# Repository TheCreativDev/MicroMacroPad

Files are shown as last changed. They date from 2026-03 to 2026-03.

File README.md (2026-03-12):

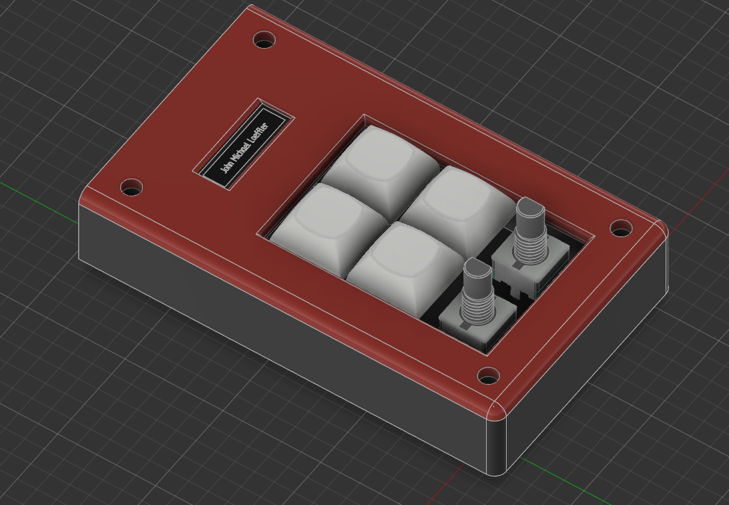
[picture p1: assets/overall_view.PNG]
MiniMacroPad


# Micro-Macro-Pad!

A small design with 4 Switches and 2 Rotary Encoders for maximum freedom with hotkeys. It's the first hardware I designed, and the first time I worked with both KiCad and Autodesk Fusion, but which was easy and fun to get started thanks to the resources on https://blueprint.hackclub.com/hackpad

## Features
- runs on KMK
- added a little animation that flashes the OLED in a wave pattern on every keystroke

## BOM
- 1 Seeed XIAO RP2040
- 4 MX-Style Switches
- 4 blank DSA keycaps
- 2 EC11 Rotary encoders
- 1 0.91 inch OLED display
- 5 M3x16mm screws
- 5 M3x5mmx4mm heatset inserts
- 6 1N4148 Diodes

## Images of the pad

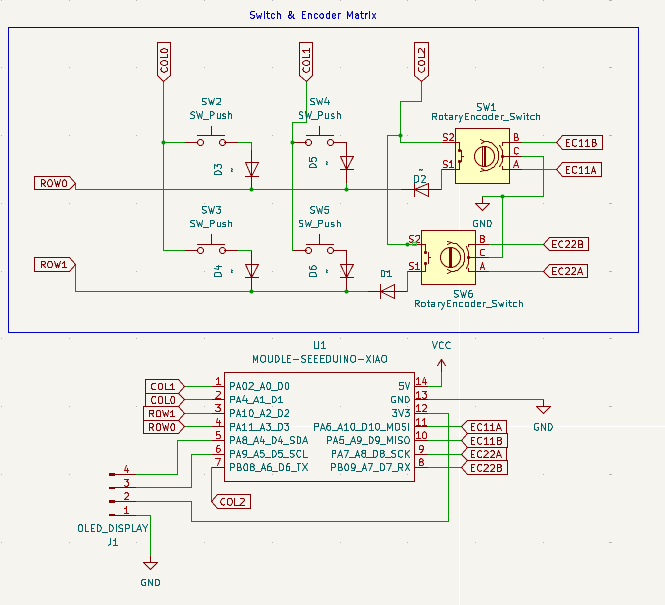
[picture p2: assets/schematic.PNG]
Schematic

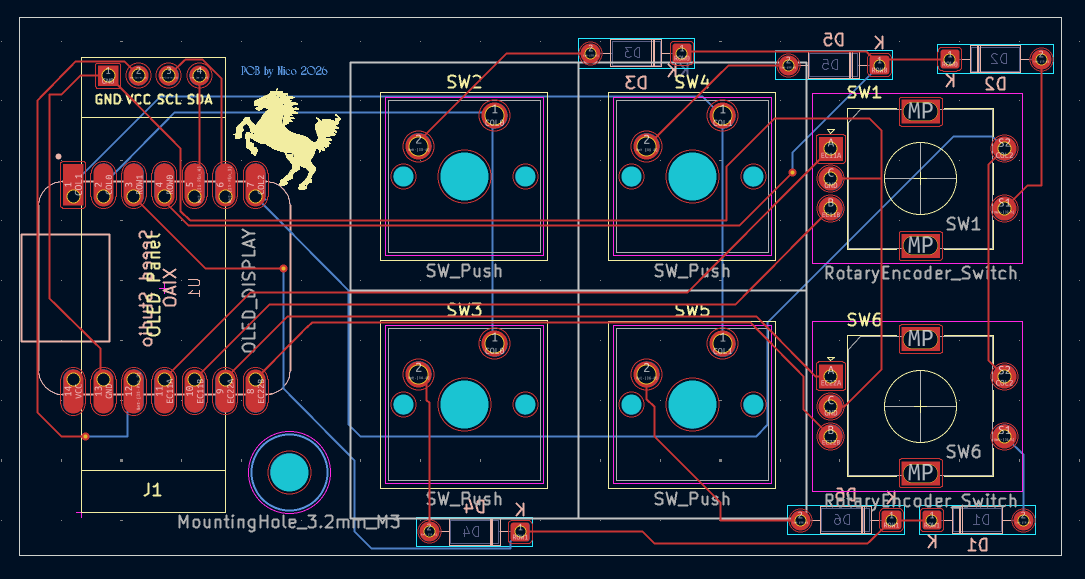
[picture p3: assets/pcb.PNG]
PCB

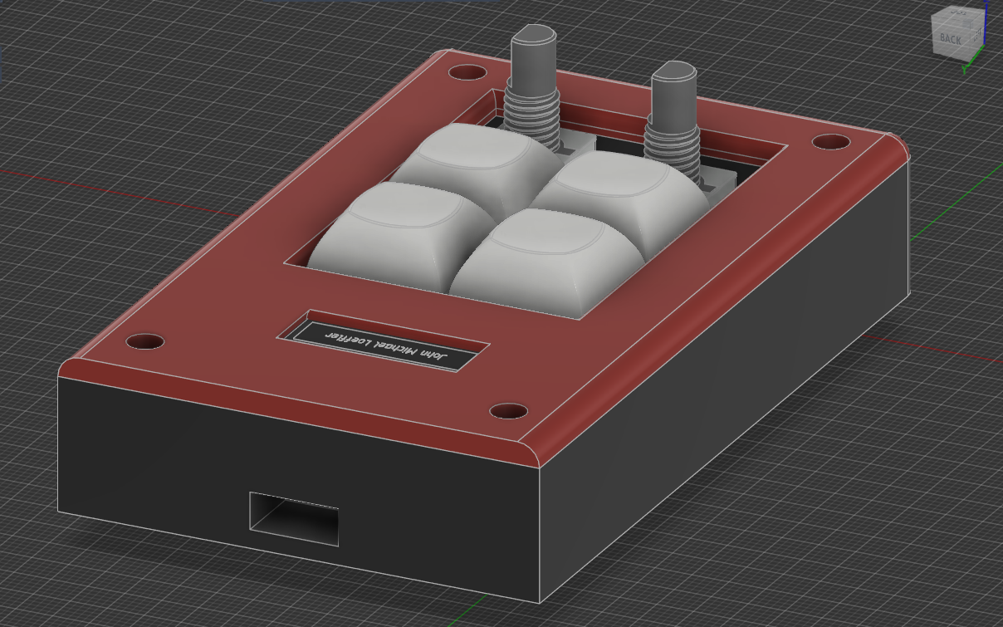
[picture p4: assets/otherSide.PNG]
Case1

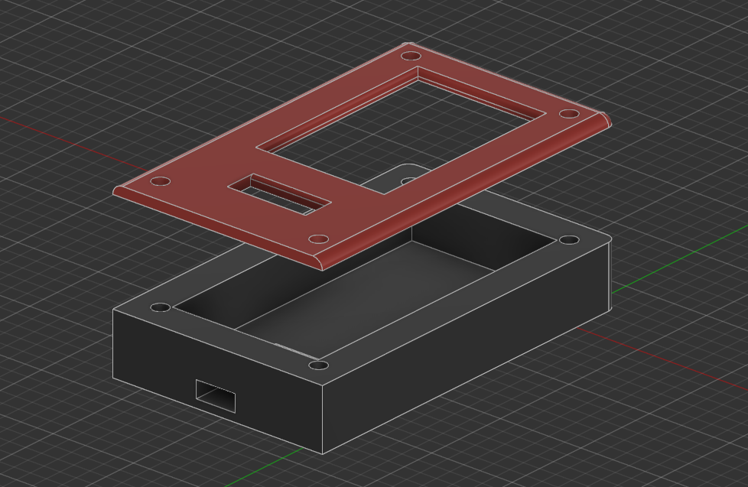
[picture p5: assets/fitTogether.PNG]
Case2


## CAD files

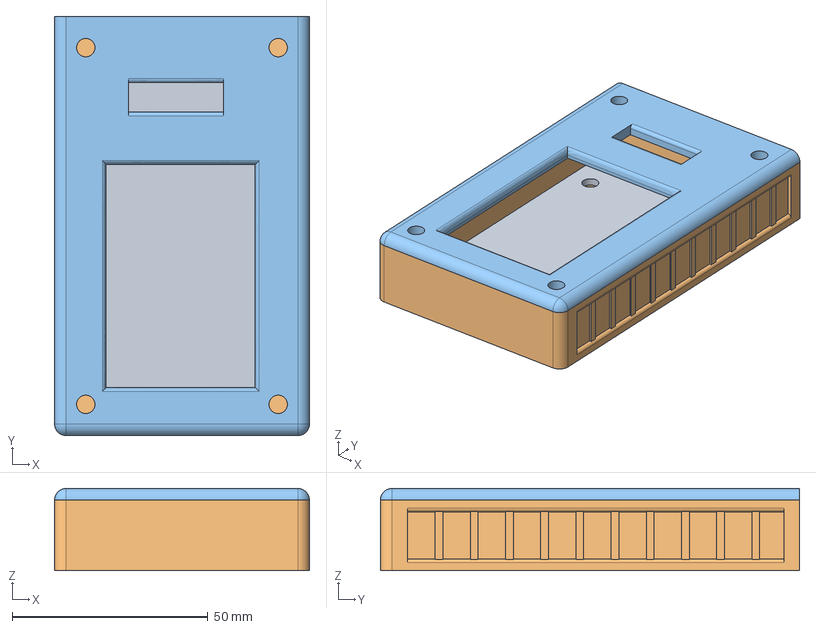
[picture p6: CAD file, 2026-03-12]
cad/assembled case.step
65.2 x 107.2 x 21.0 mm

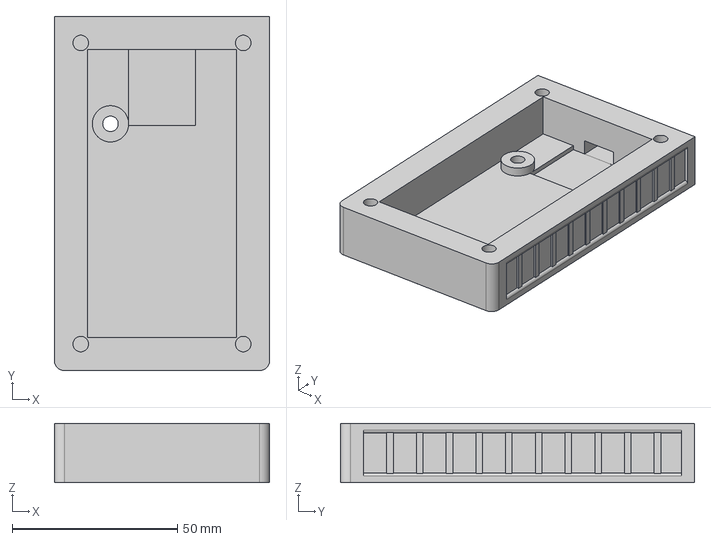
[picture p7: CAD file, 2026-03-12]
production/Bottom.step
65.2 x 107.2 x 18.0 mm

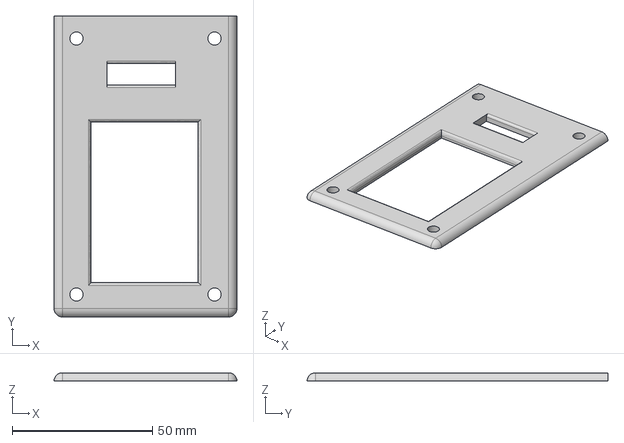
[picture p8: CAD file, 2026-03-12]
production/Top.step
65.2 x 107.2 x 3.00 mm

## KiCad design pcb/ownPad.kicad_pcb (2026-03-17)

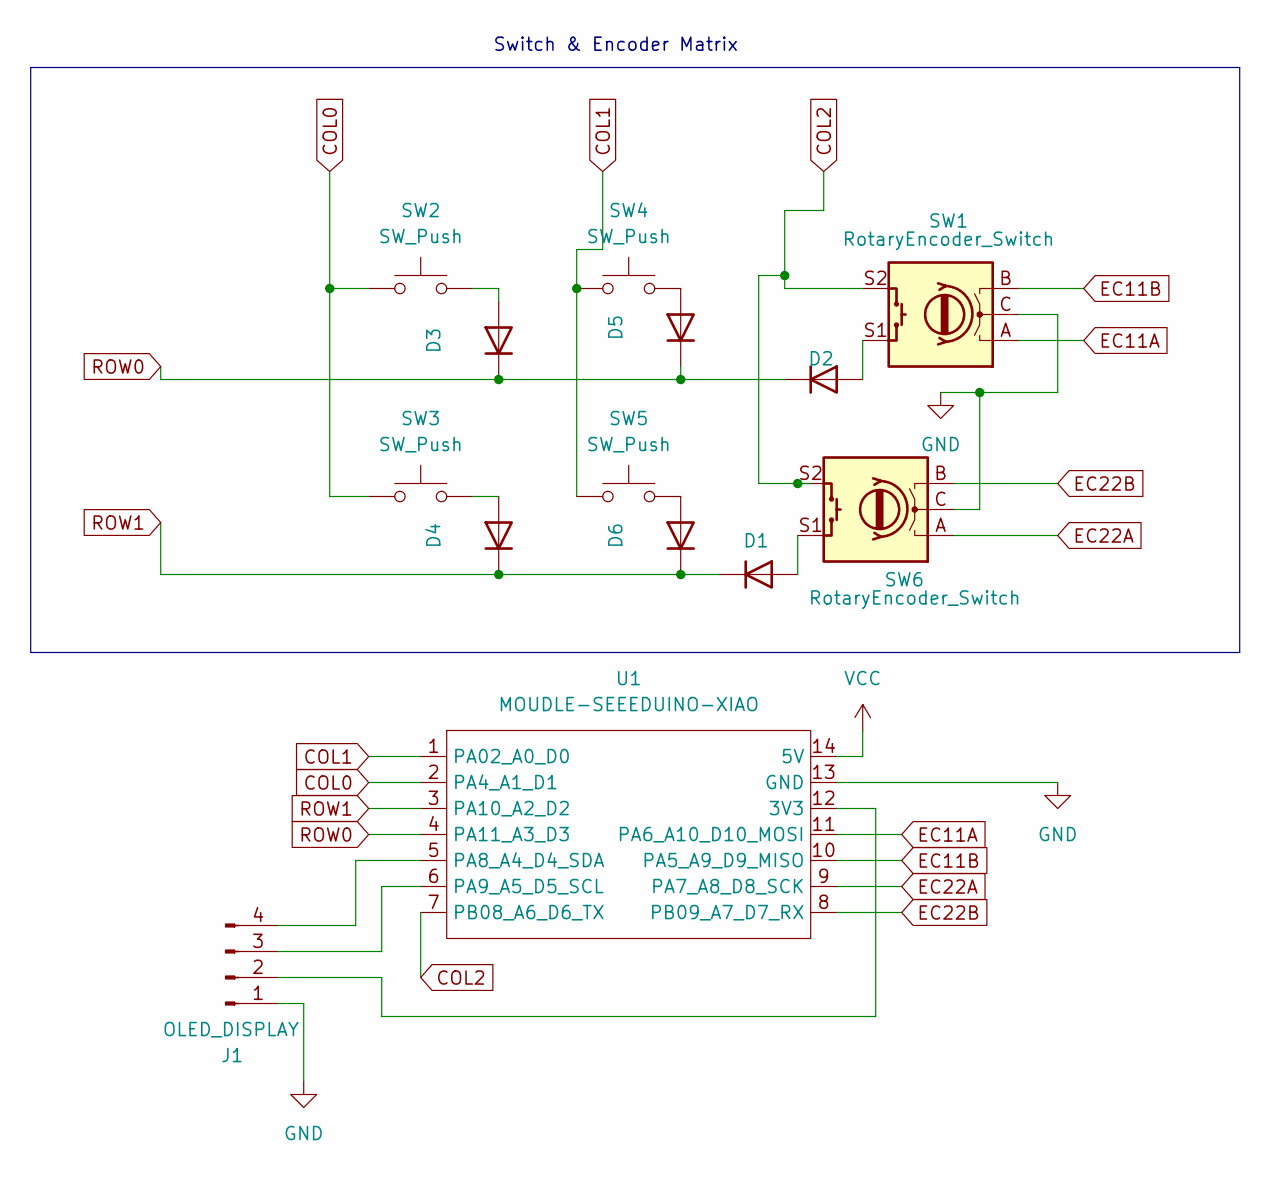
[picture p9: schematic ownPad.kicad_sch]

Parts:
D1, D2, D3, D4, D5, D6: D_DO-35_SOD27_P7.62mm_Horizontal
J1: OLED_DISPLAY; SSD1306-0.91-OLED-4pin-128x32
SW1, SW6: RotaryEncoder_Switch; RotaryEncoder_Alps_EC11E-Switch_Vertical_H20mm
SW2, SW3, SW4, SW5: SW_Push; SW_Cherry_MX_1.00u_PCB
U1: MOUDLE-SEEEDUINO-XIAO; XIAO-Generic-Hybrid-14P-2.54-21X17.8MM

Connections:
COL0: SW2.1, SW3.1, U1.2 (PA4_A1_D1)
COL1: SW4.1, SW5.1, U1.1 (PA02_A0_D0)
COL2: SW1.S2, SW6.S2, U1.7 (PB08_A6_D6_TX)
EC11A: SW1.A, U1.11 (PA6_A10_D10_MOSI)
EC11B: SW1.B, U1.10 (PA5_A9_D9_MISO)
EC22A: SW6.A, U1.9 (PA7_A8_D8_SCK)
EC22B: SW6.B, U1.8 (PB09_A7_D7_RX)
GND: J1.1, SW1.C, SW6.C, U1.13 (GND)
unnamed: D1.2 (A), SW6.S1
unnamed: D2.2 (A), SW1.S1
unnamed: D3.2 (A), SW2.2
unnamed: D4.2 (A), SW3.2
unnamed: D5.2 (A), SW4.2
unnamed: D6.2 (A), SW5.2
unnamed: J1.2, U1.12 (3V3)
unnamed: J1.3, U1.6 (PA9_A5_D5_SCL)
unnamed: J1.4, U1.5 (PA8_A4_D4_SDA)
ROW0: D2.1 (K), D3.1 (K), D5.1 (K), U1.4 (PA11_A3_D3)
ROW1: D1.1 (K), D4.1 (K), D6.1 (K), U1.3 (PA10_A2_D2)
VCC: U1.14 (5V)

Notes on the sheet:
Switch & Encoder Matrix

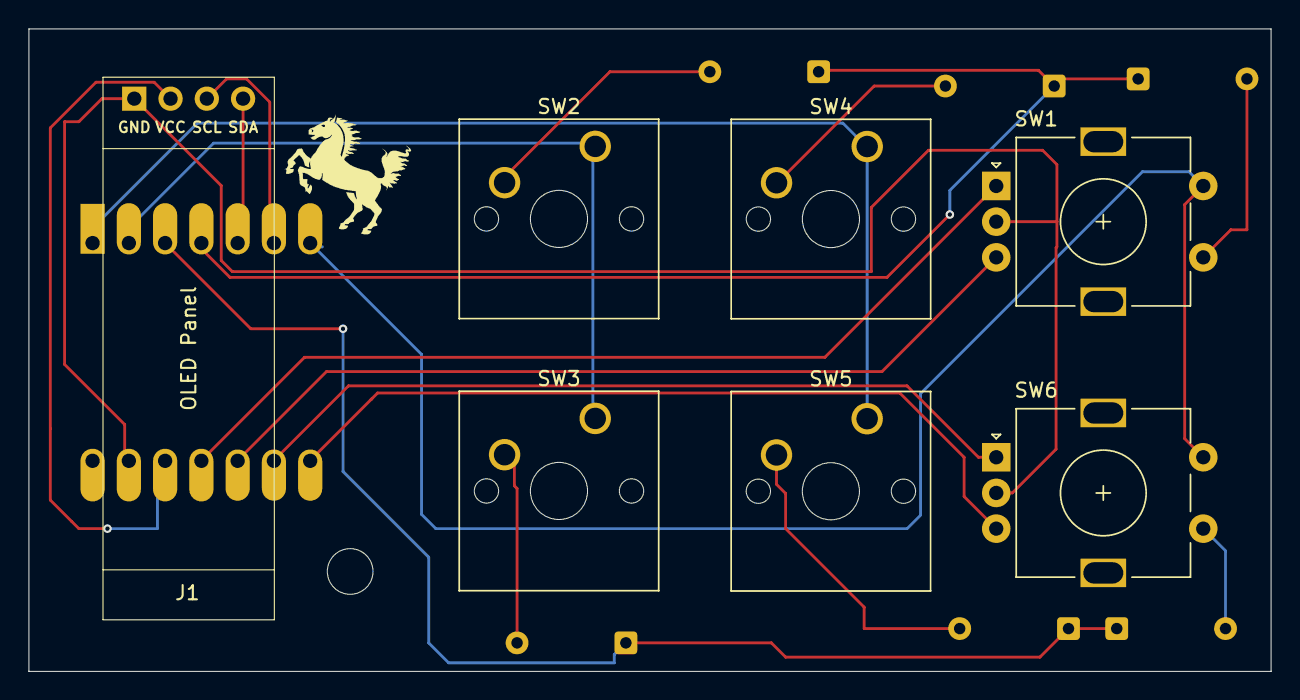
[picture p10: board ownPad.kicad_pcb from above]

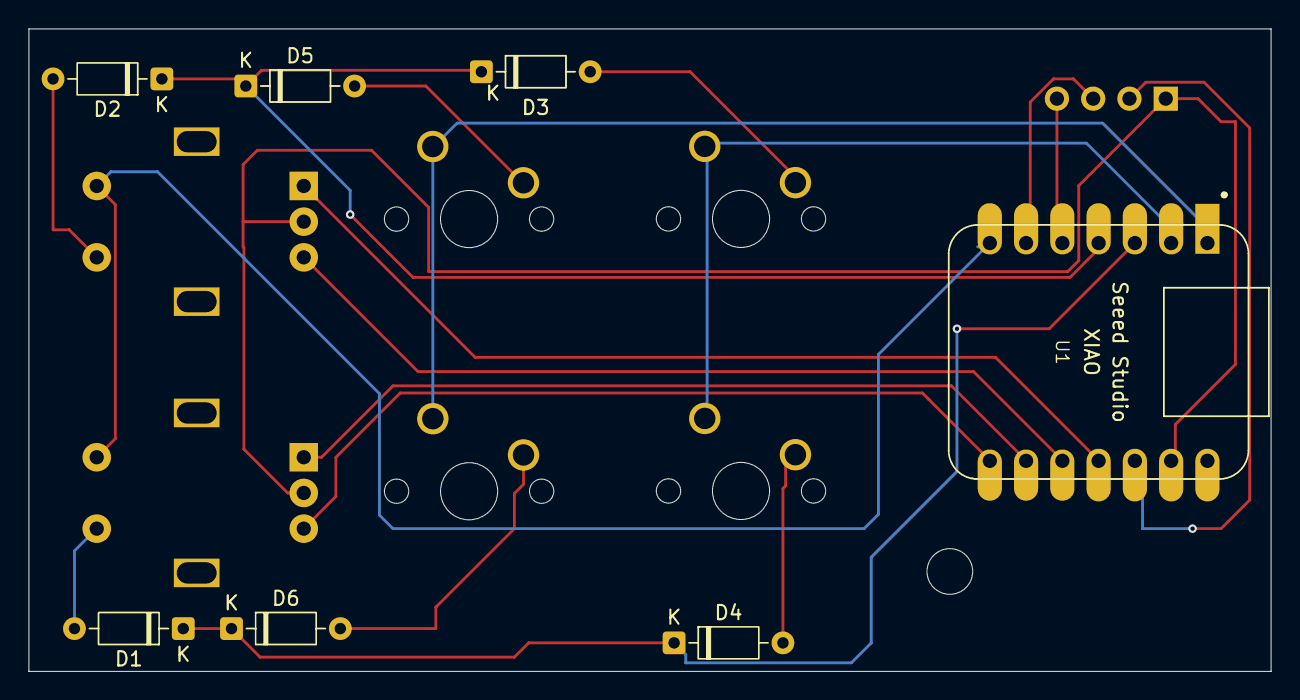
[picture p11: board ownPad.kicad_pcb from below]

Board: 2 copper layers, 87.0 x 45.0 mm, 14 parts (7 on the bottom side), 19 nets.

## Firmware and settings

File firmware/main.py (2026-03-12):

"""
Macropad Firmware mit OLED Display
Board: XIAO RP2040
Layout: 2x3 Matrix + 2 Rotary Encoders + 0.91" 128x32 OLED Display
"""

import board
import busio
import time

from kmk.kmk_keyboard import KMKKeyboard
from kmk.keys import KC
from kmk.scanners import DiodeOrientation
from kmk.modules.encoder import EncoderHandler

# OLED Display
try:
    import adafruit_ssd1306
    from PIL import Image, ImageDraw
    DISPLAY_AVAILABLE = True
except ImportError:
    DISPLAY_AVAILABLE = False

keyboard = KMKKeyboard()

keyboard.row_pins = (
    board.GP3,
    board.GP2,
)

keyboard.col_pins = (
    board.GP1,
    board.GP0,
    board.GP6,
)

keyboard.diode_orientation = DiodeOrientation.COL2ROW

encoder_handler = EncoderHandler()

encoder_handler.pins = (
    (board.GP10, board.GP9),  # Encoder 1
    (board.GP8, board.GP7),  # Encoder 2
)

"""
Format:
((CCW, CW),(CCW,CW))

CCW = counter clockwise
CW  = clockwise
"""

encoder_handler.map = (
    ((KC.VOLD, KC.VOLU)),      # Encoder 1 Lautstärke
    ((KC.LEFT, KC.RIGHT)),     # Encoder 2 Cursor
)

keyboard.modules.append(encoder_handler)

if DISPLAY_AVAILABLE:
    # I2C Pins: SCL=GP5, SDA=GP4
    i2c = busio.I2C(board.GP5, board.GP4)
    oled = adafruit_ssd1306.SSD1306_I2C(128, 32, i2c, addr=0x3C)
    
    # Wave Effekt Config
    wave_active = False
    wave_start_time = 0.0
    wave_duration = 0.5  # sek
    
    def trigger_wave():
        global wave_active, wave_start_time
        wave_active = True
        wave_start_time = time.monotonic()
    
    def render_wave():
        global wave_active
        
        if not wave_active:
            return
        
        current_time = time.monotonic()
        elapsed = current_time - wave_start_time
        
        if elapsed >= wave_duration:
            wave_active = False
            oled.fill(0)
            oled.show()
            return
        
        # Farbiges Bild erstellen (RGB für rote Welle)
        image = Image.new("RGB", (128, 32), (0, 0, 0))
        draw = ImageDraw.Draw(image)
        
        # Wellenausbreitung berechnen
        progress = elapsed / wave_duration  # 0.0 - 1.0
        max_expansion = 64  # Hälfte der Breite
        wave_width = int(progress * max_expansion)
        
        # Helligkeit abdimmen
        brightness = 255 * (1 - (progress)**2)
        
        center_x = 64  # Mitte des Displays
        
        # Welle zeichnen wenn sichtbar
        if brightness > 20:
            # Rote Farbe mit Helligkeit
            red_value = int(brightness)
            red_color = (red_value, 0, 0)
            
            # Linke Seite, expandiert nach links
            for dx in range(max(0, wave_width)):
                x = center_x - dx
                if 0 <= x < 128:
                    draw.line([(x, 0), (x, 31)], fill=red_color)
            
            # Rechte Seite, expandiert nach rechts
            for dx in range(max(0, wave_width)):
                x = center_x + dx
                if 0 <= x < 128:
                    draw.line([(x, 0), (x, 31)], fill=red_color)
                     
        
        # Bild auf Display anzeigen
        oled.image(image)
        oled.show()
    
    # Hook: Wave bei Tastendrücken triggern
    original_process_key = keyboard.process_key
    
    def new_process_key(key, is_pressed, int_coord):
        trigger_wave()
        return original_process_key(key, is_pressed, int_coord)
    
    keyboard.process_key = new_process_key

keyboard.keymap = [
    [
        KC.MUTE,   KC.PLAY,   KC.NEXT,     # obere Reihe
        KC.A,      KC.B,      KC.C         # untere Reihe
    ]
]

if __name__ == '__main__':
    if DISPLAY_AVAILABLE:
        oled.fill(0)
        oled.show()
    
    # Main Loop
    keyboard.go()

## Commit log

2026-03-15 fixed unconnected traces on pcb
    [ownPad.kicad_pcb, ownPad.kicad_sch]
2026-03-17 removed errors in pcb design
    [ownPad.kicad_pcb, ownPad.kicad_sch]
